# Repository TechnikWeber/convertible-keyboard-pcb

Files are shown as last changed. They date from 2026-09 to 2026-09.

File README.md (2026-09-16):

**English** · [Deutsch](README.de.md)

# convertible-keyboard-pcb

> ### 🔎 Looking for a case designer
> This keyboard has a PCB in progress but no case yet. If you design keyboard
> cases — 3D-printed, CNC-milled or laser-cut — and would like to take this on,
> please [open an issue](https://github.com/TechnikWeber/convertible-keyboard-pcb/issues).
> A first board outline exists (key field + 1.3 mm), but outline, mounting holes
> and the USB-C position can still be shaped around your case design — for the full-size board, the TKL, or
> both. The same goes for where exactly the lock indicators sit. The USB port
> can sit on the PCB or on a Unified Daughterboard (Pico-EZmate or JST-SH).

**One keyboard PCB, two sizes.** A full-size ISO-DE / ANSI board whose numpad
snaps off along a breakaway line. What remains is a complete tenkeyless (TKL)
keyboard — same PCB, same controller, same firmware.

This is not meant to be yet another one-off DIY keyboard. The goal is a
standardised core design that others can build on: cheap and simple to make, but
clean and modern — current KiCad, QMK, USB-C and parts that can actually be
bought. A case, lighting or layout variants build on this core instead of
bending it into something else.

> **Status: early.** The schematic is complete — key matrix, ANSI alternatives,
> backlight and controller — and every part has its footprint on the PCB.
> Controller, USB and drivers are placed on the back, board outline and breakaway
> line are drawn; mounting holes and routing are still to do.
> Nothing has been manufactured yet.

## Full-size or TKL

- The numpad sits on the right-hand side behind a 2 mm slot, held by four
  mouse-bite tabs (perforated breakaway bridges). Each tab keeps a hole-free
  channel in the middle for the traces that cross over.
- Controller, USB-C and the drivers for backlight and lock indicators all sit
  on the TKL part. Only the numpad's matrix, backlight and indicator lines cross the breakaway
  line.
- Snap the numpad off and the TKL keeps working unchanged — the numpad keys are
  simply gone. The firmware describes both layouts.
- The lock indicators above the numpad go with it – without a numpad Num Lock is
  pointless anyway; for the TKL populate the Caps Lock indicator above Page Up.
- The snapped-off numpad has no controller of its own and does not work on its
  own.

## Specs

- Full-size: 105 keys ISO-DE, key field 428.6 × 123.8 mm (22.5 × 6.5 u)
- TKL: 88 keys ISO-DE, key field 347.7 × 123.8 mm (18.25 × 6.5 u)
- ISO-DE and ANSI on one PCB: alternative positions for Enter, left Shift and
  backslash (the ANSI backslash is the only key without an LED)
- Cherry MX-compatible switches, soldered, with stabilizer holes on all keys of
  2u and wider
- 6 × 21 diode matrix (SOD-123)
- RP2040 controller with 16 Mbit QSPI flash, RESET and BOOTSEL buttons and SWD
  test pads
- USB-C (USB 2.0) on the board with ESD protection, 500 mA polyfuse and a 3.3 V
  LDO – or a Unified Daughterboard instead: connectors for Molex Pico-EZmate
  (uDB S1, C4, C5-EZM) and JST-SH (uDB C3, C5-JSH) are provided, not populated
- Single-colour backlight with reverse-mount 1206 LEDs on the back of the PCB
  (white, XINGLIGHT XL-3216UWC-FB), machine-assembled; switched, dimmed and
  "breathing" via QMK. A THT-LED variant uses the same design with different LED
  footprints
- Checked alternative backlight LEDs for the same footprint: MEIHUA MHT151WDT
  (LCSC C401114) and TUOZHAN P2-1206WYCS2-0.9T-F (LCSC C2827252)
- Caps Lock and Num Lock indicators (0805) above the numpad; for the TKL a Caps
  Lock indicator above Page Up is prepared but not populated
- All 30 RP2040 GPIOs in use: 27 matrix lines, backlight PWM, Caps Lock and
  Num Lock

## Repository

| Path | Contents |
|---|---|
| `convertible-keyboard-pcb.kicad_pro` / `.kicad_pcb` | KiCad 10 project and PCB |
| `convertible-keyboard-pcb.kicad_sch` | Root sheet: key matrix and ANSI alternatives |
| `backlight.kicad_sch` | Key LEDs, series resistors and MOSFET drivers |
| `mcu.kicad_sch` | RP2040, flash, crystal, USB-C and power |
| `lib/keyboard.pretty` | Project footprints: reverse-mount LED, THT LED for the variant |
| `fp-lib-table`, `convertible-keyboard-pcb.kicad_dru` | Footprint library table, design rule for the LED cutouts |
| `lib/MX_Alps_Hybrid` | Switch footprints by ai03 (git submodule) |
| `tools/` | Scripts that generated the sheets and updated the PCB – see [tools/README.md](tools/README.md) |
| `docs/production/` | Gerbers, drill file, BOM and placement file for JLCPCB |
| `firmware/` | QMK keyboard definition and keymaps – see [firmware/README.md](firmware/README.md) |

The footprints come from a submodule, so clone with:

```bash
git clone --recurse-submodules https://github.com/TechnikWeber/convertible-keyboard-pcb.git
```

## What it looks like

These renders let you review the design without installing KiCad.

### Key layouts

Everything is built around these two: ISO-DE with 105 keys and ANSI with 104. The board carries both. The ANSI
positions are alternative footprints that stay unpopulated on an ISO build, and the other way round.

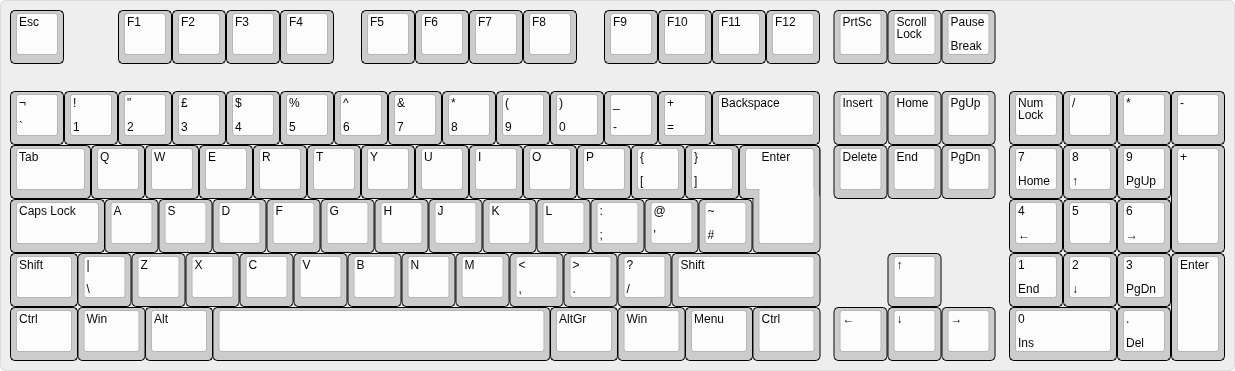
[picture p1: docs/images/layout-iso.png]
ISO-DE layout


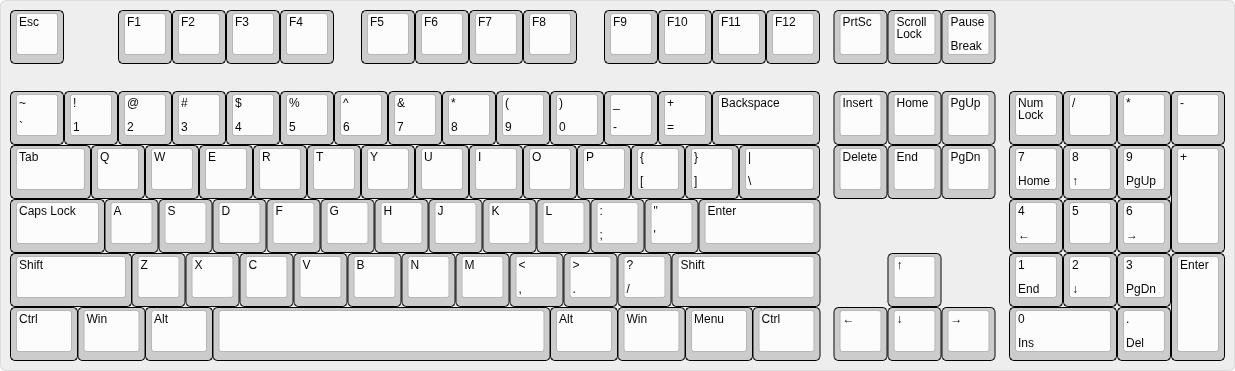
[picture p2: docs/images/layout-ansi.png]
ANSI layout


### Board in 3D

Switch side: through holes for the switches and their stabilisers, no components. Note the breakaway line in
front of the numpad.

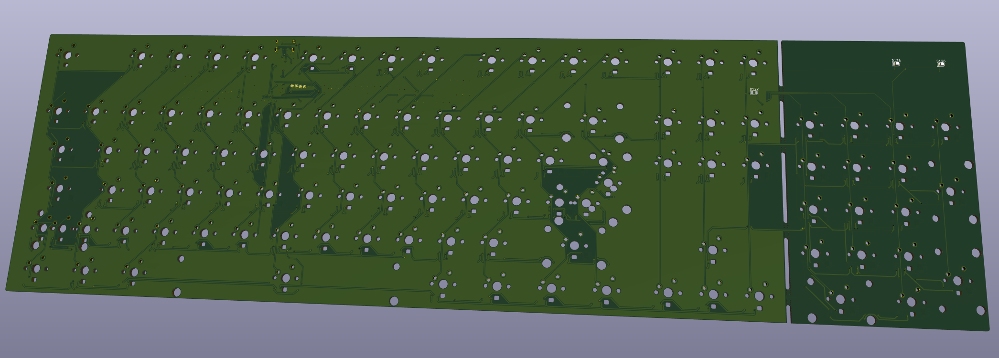
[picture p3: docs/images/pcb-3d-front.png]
3D, switch side


Component side: nearly everything sits here. Diodes and resistors per key, the reverse-mount LEDs shining
through their cutouts, and the controller in the gap between F4 and F5. The only parts on the other side are
the two lock indicators above the numpad.

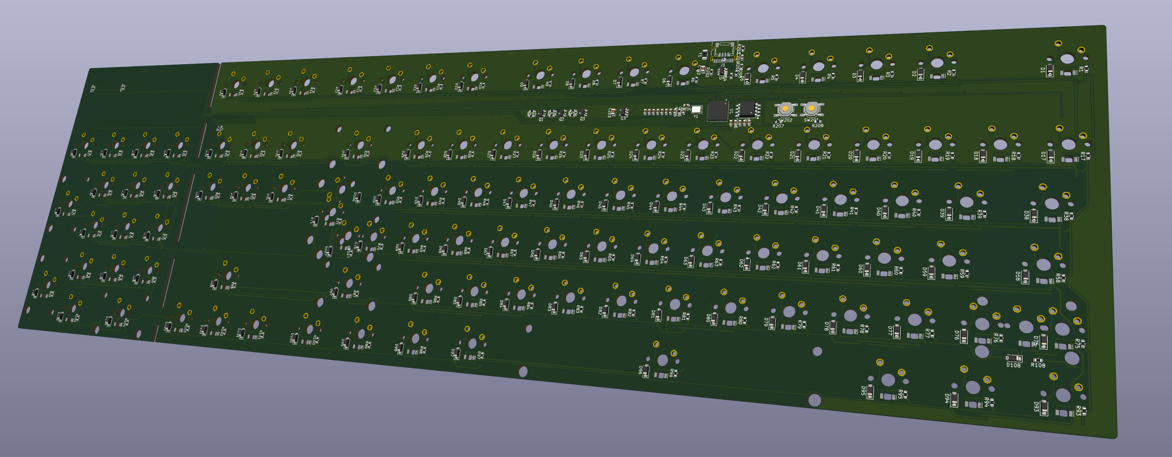
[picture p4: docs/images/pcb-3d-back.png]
3D, component side


### Board

Both copper layers, zone fills hidden so the traces stay readable. The numpad on the right snaps off along the
breakaway line; only matrix lines, +5V, BL_K and the two lock-LED lines cross it, through the four tabs.

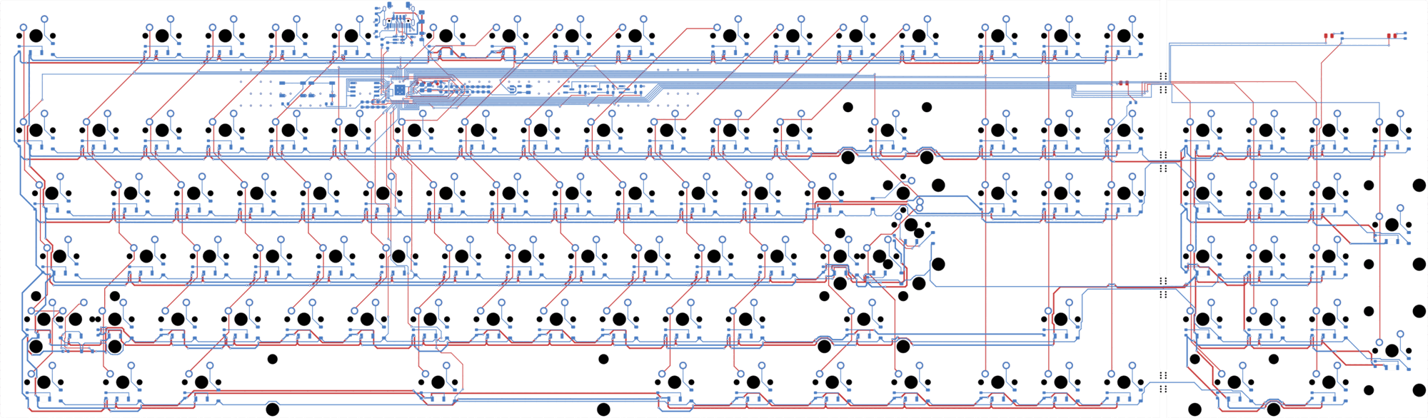
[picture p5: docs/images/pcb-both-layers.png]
Both copper layers


The controller sits in the gap between F4 and F5. Column and row buses run in fixed lanes and each one ends on a
via that drops onto the column trace of its key. Every SMD part in this area is on the back.

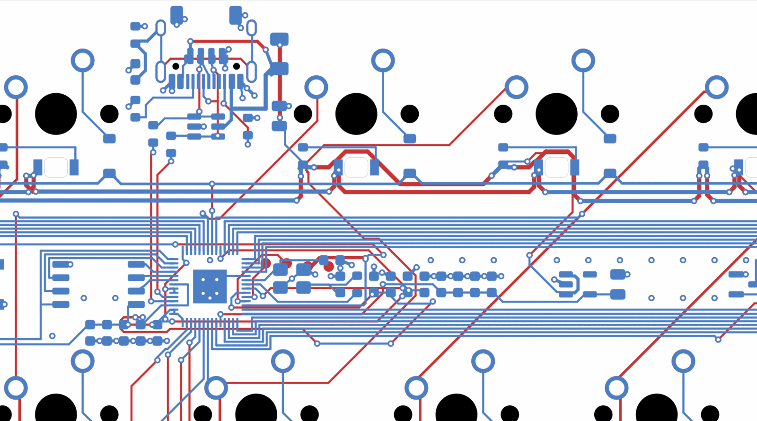
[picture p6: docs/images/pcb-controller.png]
Controller area


Front (switch side, mostly through holes and the key matrix) and back (all components, reverse-mount LEDs):

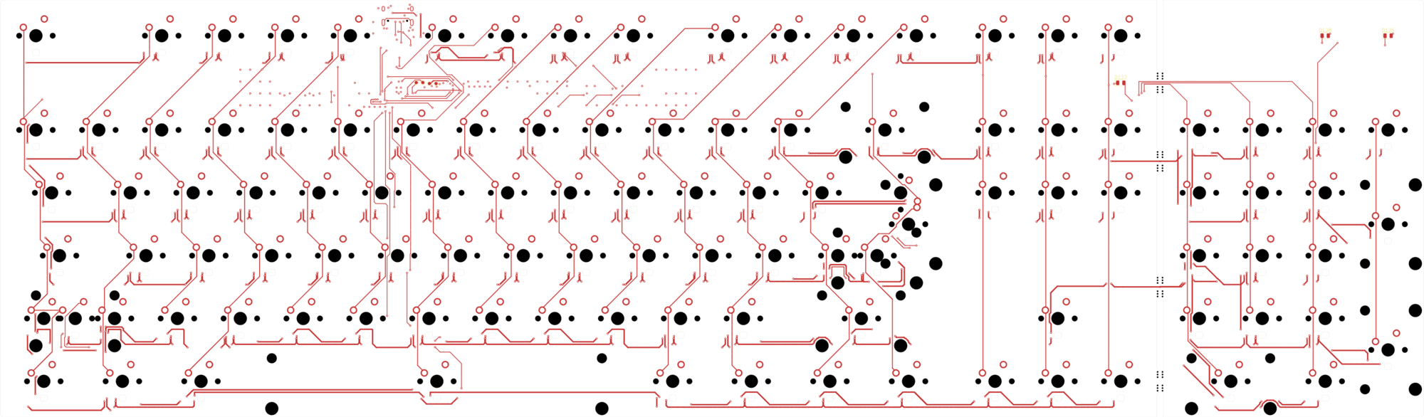
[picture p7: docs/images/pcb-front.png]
Front


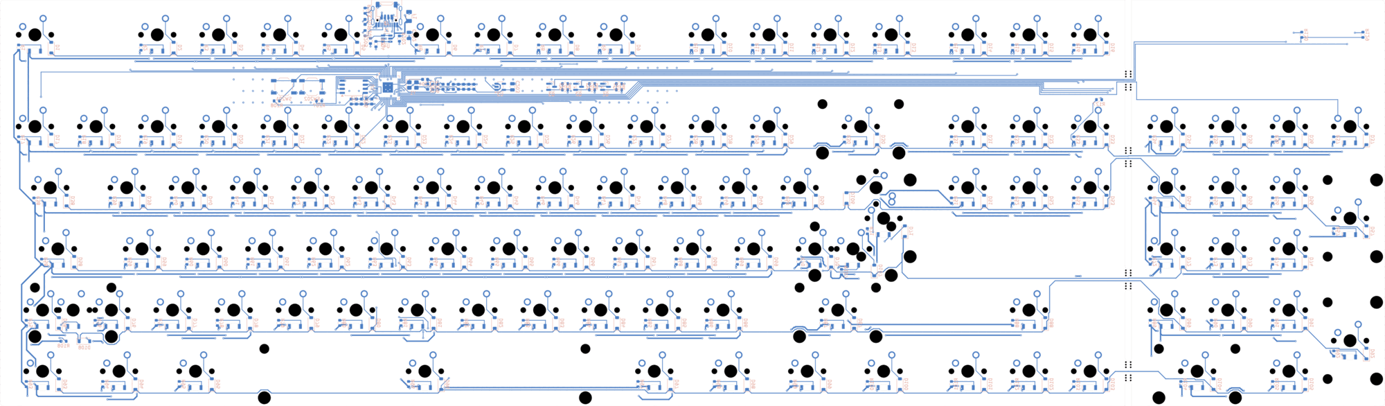
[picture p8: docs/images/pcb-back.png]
Back


### Schematic

Key matrix with the ANSI alternatives:

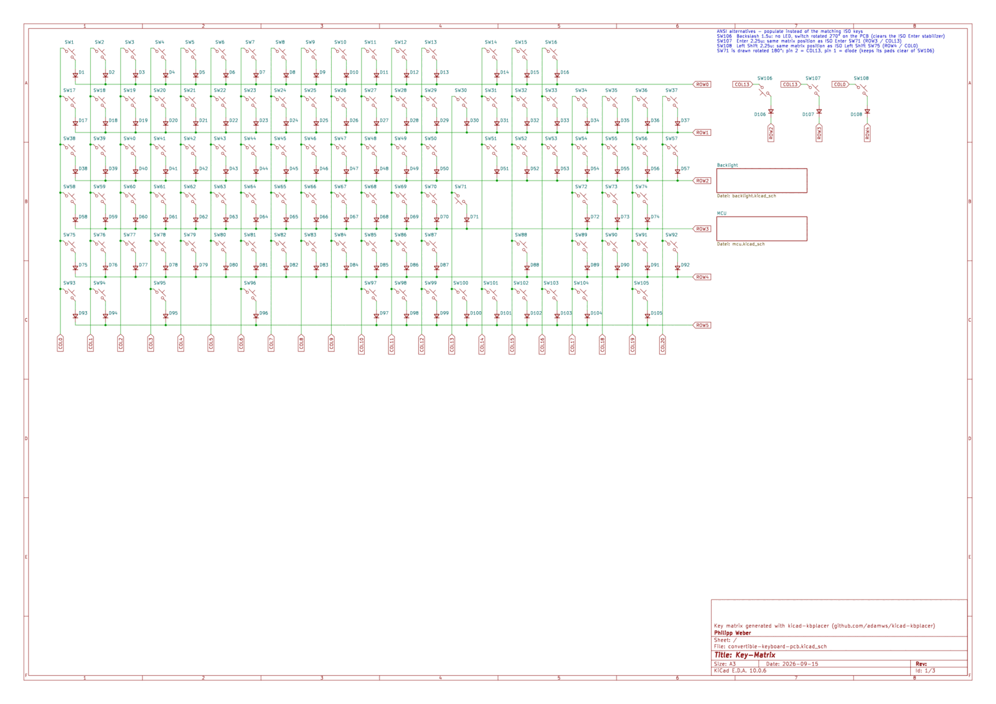
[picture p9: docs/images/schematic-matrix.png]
Matrix


Backlight, lock indicators and their drivers:

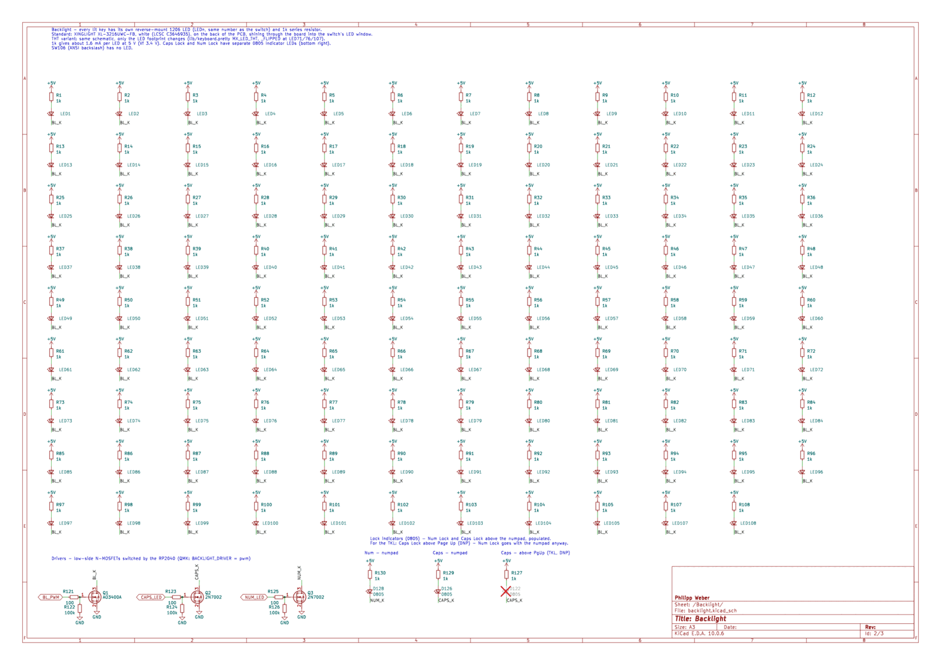
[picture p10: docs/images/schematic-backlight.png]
Backlight


Controller: RP2040, flash, crystal, LDO, USB-C with ESD protection, daughterboard connectors, buttons, test pads:

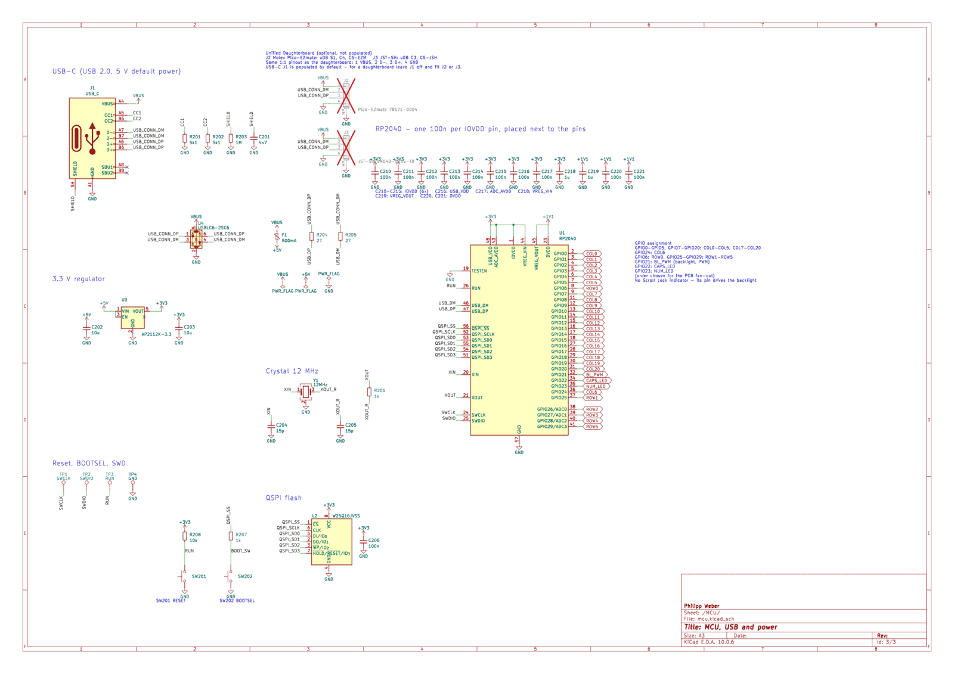
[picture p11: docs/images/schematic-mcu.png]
Controller


## Having it made

Gerbers, drill file, BOM and placement file for JLCPCB are in
[`docs/production/`](docs/production/README.md), all generated from the KiCad project. The board is
431.225 × 126.425 mm on two layers. 371 parts are machine-assembled; the 108 MX switches are soldered by
hand, and three parts are deliberately left unpopulated.

JLCPCB's minimum order is 5 boards: **$45 for five bare PCBs**, or **$112 for five with two of them
assembled** (checked 2026-09-16, shipping in, customs out). Switches, keycaps and a case come on top.

Nothing here has been built in hardware yet. The files pass DRC and schematic parity, nothing more —
review them before you spend money.

## Roadmap

- [x] Key matrix and diodes
- [x] Footprints for all key sizes
- [x] ANSI alternative positions
- [x] Single-colour backlight
- [x] Controller sheet: RP2040, flash, crystal, LDO, USB-C, ESD protection
- [x] Breakaway line for the numpad
- [x] Board outline (first draft)
- [x] Mounting holes: 14 × M2, placed in the free areas; final positions together with the case designer
- [x] Placement of controller, USB and drivers (preliminary)
- [x] Routing complete: key matrix and controller area (DRC clean, schematic parity clean, no open nets)
- [x] Manufacturing files for JLCPCB: gerbers, drill, BOM and placement file, an LCSC number on every part
- [x] Firmware (QMK): four layouts (full-size and TKL, each ISO and ANSI), matrix generated from the
      board file, backlight and lock indicators; compiles, not yet run on hardware

## Licence

CC BY-NC-SA 4.0 — see [LICENSE](LICENSE). The switch footprints in
`lib/MX_Alps_Hybrid` are by ai03 under the MIT License;
the THT LED footprints in `lib/keyboard.pretty` use their pad geometry.

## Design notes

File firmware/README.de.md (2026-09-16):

[English](README.md) · **Deutsch**

# Firmware (QMK)

QMK-Definition für die convertible-keyboard-pcb. Die Matrixzuordnung und die
Tastenreihenfolge aller Layout-Makros werden **aus der KiCad-Platine erzeugt**,
nicht von Hand getippt — die Firmware kann also nicht von der Platine
abdriften.

> **Kompiliert, aber noch nie auf Hardware gelaufen.** Alle vier Varianten
> bauen bis zum `.uf2` durch, `qmk lint` ist sauber. Es gibt noch keine Platine,
> auf der sie sich testen ließen.

## Layouts

| Layout-Makro | Tasten | Keymap-Ordner |
|---|---|---|
| `LAYOUT_fullsize_iso` | 105 | `keymaps/default` |
| `LAYOUT_fullsize_ansi` | 104 | `keymaps/fullsize_ansi` |
| `LAYOUT_tkl_iso` | 88 | `keymaps/tkl_iso` |
| `LAYOUT_tkl_ansi` | 87 | `keymaps/tkl_ansi` |

Die TKL-Varianten sind die, die man **nach** dem Abbrechen des Ziffernblocks
aufspielt. Alle vier sind als QMK-Community-Layouts angemeldet, fremde Keymaps
für andere `fullsize_iso`- oder `tkl_ansi`-Tastaturen laufen also unverändert.

## Bauen

Dieser Ordner ist die Quelle. Ihn in eine QMK-Arbeitskopie verlinken, statt zu
kopieren:

```sh
git clone --depth 1 --recurse-submodules https://github.com/qmk/qmk_firmware.git
mkdir -p qmk_firmware/keyboards/technikweber
ln -s "$(pwd)/technikweber/convertible" qmk_firmware/keyboards/technikweber/convertible

python3 -m venv qmkenv && ./qmkenv/bin/pip install qmk
export QMK_HOME="$(pwd)/qmk_firmware"
./qmkenv/bin/qmk compile -kb technikweber/convertible -km default
```

Statt `-km default` auch `fullsize_ansi`, `tkl_iso` oder `tkl_ansi`. Es braucht
eine `arm-none-eabi-gcc`; jede generische ARM-Toolchain genügt, es muss nicht
die aus QMKs eigenem Installationsskript sein.

## Aufspielen

Die Platine in den Bootloader bringen — Esc beim Einstecken halten, `SW201` auf
der Rückseite drücken, `SW202` (BOOTSEL) beim Einstecken halten oder `Fn` + `Esc`
— dann die `.uf2` auf das erscheinende Laufwerk `RPI-RP2` kopieren, oder statt
`qmk compile` einfach `qmk flash` benutzen.

## Fn-Ebene

`Fn` liegt auf der Menü-Taste, die unter ISO-DE praktisch ungenutzt ist. Die
Menü-Funktion selbst bleibt als `Fn` + Menü erreichbar.

| Taste | Funktion |
|---|---|
| `Fn` + `Esc` | Bootloader |
| `Fn` + `F1` | Beleuchtung an/aus |
| `Fn` + `F2` / `F3` | dunkler / heller |
| `Fn` + `F4` | Breathing an/aus |

## Zuordnung zur Hardware

21 Spalten × 6 Reihen, Dioden `COL2ROW`. Alle 30 GPIOs sind belegt: `GP0`–`GP5`
und `GP7`–`GP20` plus `GP24` für die Spalten, `GP6` und `GP25`–`GP29` für die
Reihen, `GP21` Beleuchtung, `GP22` Caps Lock, `GP23` Num Lock.

Die Beleuchtung läuft über PWM. Beim RP2040 gehört ein GPIO zum Slice
`(n / 2) % 8`, Kanal A bei geradem und B bei ungeradem Pin — `GP21` braucht
also `PWMD2` und Kanal B, genau das setzt `config.h`, während `halconf.h` und
`mcuconf.h` die Peripherie freischalten. Ohne diese drei Dateien fällt der Bau
auf eine STM32-Vorgabe (`PWMD4`) zurück und scheitert.

## USB-VID/PID

`0xFEED` / `0x0001` sind QMKs Platzhalter und kollidieren mit vielen anderen
Tastaturen. Zum Testen in Ordnung; wer das in Stückzahl baut, sollte eigene
Kennungen anmelden.

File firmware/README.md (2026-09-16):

**English** · [Deutsch](README.de.md)

# Firmware (QMK)

QMK keyboard definition for the convertible-keyboard-pcb. The matrix assignment
and the key order of every layout macro are **generated from the KiCad board
file**, not typed by hand — so the firmware cannot drift away from the PCB.

> **Compiled, not yet run on hardware.** All four variants build to a `.uf2`,
> and `qmk lint` passes. No board exists yet to test them on.

## Layouts

| Layout macro | Keys | Keymap folder |
|---|---|---|
| `LAYOUT_fullsize_iso` | 105 | `keymaps/default` |
| `LAYOUT_fullsize_ansi` | 104 | `keymaps/fullsize_ansi` |
| `LAYOUT_tkl_iso` | 88 | `keymaps/tkl_iso` |
| `LAYOUT_tkl_ansi` | 87 | `keymaps/tkl_ansi` |

The TKL variants are the ones to flash **after** snapping the numpad off. All
four are registered as QMK community layouts, so keymaps written for any other
`fullsize_iso` or `tkl_ansi` board can be used as-is.

## Building

This folder is the source of truth. Link it into a QMK checkout rather than
copying it:

```sh
git clone --depth 1 --recurse-submodules https://github.com/qmk/qmk_firmware.git
mkdir -p qmk_firmware/keyboards/technikweber
ln -s "$(pwd)/technikweber/convertible" qmk_firmware/keyboards/technikweber/convertible

python3 -m venv qmkenv && ./qmkenv/bin/pip install qmk
export QMK_HOME="$(pwd)/qmk_firmware"
./qmkenv/bin/qmk compile -kb technikweber/convertible -km default
```

Swap `-km default` for `fullsize_ansi`, `tkl_iso` or `tkl_ansi`. An
`arm-none-eabi-gcc` is required; any generic ARM build works, it does not have
to be the one from QMK's own installer.

## Flashing

Put the board into the bootloader — hold Escape while plugging it in, press
`SW201` on the back, hold `SW202` (BOOTSEL) while plugging in, or press
`Fn` + `Escape` — then drop the `.uf2` onto the `RPI-RP2` drive that appears, or
run `qmk flash` instead of `qmk compile`.

## Fn layer

`Fn` sits on the Menu key, which is unused on most ISO-DE setups. The Menu key
itself stays reachable as `Fn` + Menu.

| Key | Function |
|---|---|
| `Fn` + `Esc` | Bootloader |
| `Fn` + `F1` | Backlight on/off |
| `Fn` + `F2` / `F3` | Dimmer / brighter |
| `Fn` + `F4` | Breathing on/off |

## Hardware mapping

21 columns × 6 rows, diodes `COL2ROW`. All 30 GPIOs are in use: `GP0`–`GP5` and
`GP7`–`GP20` plus `GP24` for the columns, `GP6` and `GP25`–`GP29` for the rows,
`GP21` backlight, `GP22` Caps Lock, `GP23` Num Lock.

The backlight runs on PWM. On RP2040 a GPIO maps to slice `(n / 2) % 8`, channel
A on even and B on odd pins — `GP21` therefore needs `PWMD2` and channel B,
which is what `config.h` sets, with `halconf.h` and `mcuconf.h` enabling the
peripheral. Without those three files the build falls back to an STM32 default
(`PWMD4`) and fails.

## USB VID/PID

`0xFEED` / `0x0001` are QMK's placeholders and collide with plenty of other
boards. They are fine for testing; anyone producing these in numbers should
register their own.

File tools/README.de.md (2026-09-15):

[English](README.md) · **Deutsch**

# tools

Skripte, mit denen die Schaltplanblätter erzeugt und die Platine für
ANSI-Alternativen, Beleuchtung und Controller aktualisiert wurden. Sie bleiben im
Repository, damit der Entwurf nachvollziehbar ist und man darauf aufbauen kann.

> **Maßgeblich sind die KiCad-Dateien.** `build.sh` beginnt wieder beim
> kbplacer-Basis-Commit und überschreibt Schaltplan und Platine – alles, was
> seitdem in KiCad von Hand geändert wurde, geht verloren. Also auf einem Branch
> verwenden, oder um den erzeugten Stand vor Beginn des Layouts nachzubauen und
> zu erweitern.
>
> Der erzeugte Stand endet mit Commit `2eb5d4f`. Spätere Änderungen – Titelblöcke
> und Blattgrößen, die reduzierten Lock-Anzeigen – wurden direkt in KiCad gemacht.

## Ablauf

| Datei | Aufgabe |
|---|---|
| `build.sh --overwrite` | Führt die drei Schritte unten aus; verweigert den Start, solange KiCad das Projekt geöffnet hat |
| `gen_sch.py <Stufe>` | Baut den Schaltplan auf dem kbplacer-Hauptblatt auf (Basis-Commit `95ce8fa`). Stufe 1: ANSI-Alternativen, 2: Beleuchtung, 3: MCU-Blatt. Schreibt auch `lib/keyboard.kicad_sym` und `sym-lib-table`. UUIDs sind deterministisch |
| `check_sch.py` | Normalisiert die Dateien (`kicad-cli sch upgrade`), führt den ERC aus, exportiert die Netzliste und prüft jede erzeugte Verbindung gegen ihr Soll-Netz |
| `sync_pcb.py` | Aktualisiert die Platine aus der Netzliste wie „PCB aus Schaltplan aktualisieren“: tauscht und ergänzt Footprints, setzt Dioden und LED-Widerstände neben ihren Schalter, verknüpft Footprints mit Symbolen, vergibt Netze, führt den DRC mit Schaltplan-Parität aus |
| `place_override.json` | Dioden-/Widerstandspositionen, die von der Standardlage neben dem Schalter abweichen (ISO/ANSI-Kollisionen) |
| `kicadlib.py` | Minimaler S-Expression-Parser/-Serializer und Hilfen für Symbolbibliotheken |
| `led_variant.py smd\|tht` | Stellt die Tasten-LEDs in den aktuellen KiCad-Dateien zwischen Reverse-Mount-SMD (Standard) und THT um – nur die LED-Footprints ändern sich; führt ERC und DRC aus |
| `analysis/` | Kollisionsprüfungen zwischen ISO- und ANSI-Footprints, aus denen der gedrehte, unbeleuchtete ANSI-Backslash und die gespiegelten LED-Pads folgen |

## Verwendung

```bash
tools/build.sh --overwrite
```

Voraussetzungen: KiCad 10 mit `kicad-cli` und dem Python-Modul `pcbnew` sowie die
Git-Historie (die Basisdateien werden mit `git show` gelesen). Zwischendateien
landen in `tools/build/`.

pcbnew vergibt neu eingefügten Footprints frische UUIDs, deshalb ändert sich die
Platinendatei bei jedem Lauf, auch wenn elektrisch alles gleich bleibt; die
Schaltplandateien entstehen exakt gleich.

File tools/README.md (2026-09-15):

**English** · [Deutsch](README.de.md)

# tools

Scripts that generated the schematic sheets and updated the PCB for the ANSI
alternatives, the backlight and the controller. They are kept so the design can
be traced and built upon.

> **The KiCad files are the source of truth.** `build.sh` starts again from the
> kbplacer base commit and overwrites schematic and PCB – any manual work done in
> KiCad since then is lost. Use it on a branch, or to reproduce and extend the
> generated state before the layout begins.
>
> The generated state ends at commit `2eb5d4f`. Later changes – title blocks and
> sheet sizes, the reduced lock indicators – were made directly in KiCad.

## Pipeline

| File | What it does |
|---|---|
| `build.sh --overwrite` | Runs the three steps below; refuses to run while KiCad has the project open |
| `gen_sch.py <stage>` | Builds the schematic on top of the kbplacer root sheet (base commit `95ce8fa`). Stage 1: ANSI alternatives, 2: backlight, 3: MCU sheet. Also writes `lib/keyboard.kicad_sym` and `sym-lib-table`. UUIDs are deterministic |
| `check_sch.py` | Normalises the files (`kicad-cli sch upgrade`), runs ERC, exports the netlist and checks every generated connection against its expected net |
| `sync_pcb.py` | Updates the PCB from the netlist like "Update PCB from Schematic": swaps and adds footprints, places diodes and LED resistors next to their switch, links footprints to symbols, assigns nets, runs DRC with schematic parity |
| `place_override.json` | Diode/resistor positions that differ from the default next to the switch (ISO/ANSI collisions) |
| `kicadlib.py` | Minimal S-expression parser/serializer and symbol-library helpers |
| `led_variant.py smd\|tht` | Switches the key LEDs between reverse-mount SMD (standard) and THT on the current KiCad files – only the LED footprints change; runs ERC and DRC |
| `analysis/` | Collision checks between ISO and ANSI footprints that led to the rotated, unlit ANSI backslash and the flipped LED pads |

## Usage

```bash
tools/build.sh --overwrite
```

Requires KiCad 10 with `kicad-cli` and the `pcbnew` Python module, and the git
history (the base files are read with `git show`). Intermediate files go to
`tools/build/`.

pcbnew gives newly added footprints fresh UUIDs, so the PCB file changes on every
run even when nothing changed electrically; the schematic files are reproduced
exactly.

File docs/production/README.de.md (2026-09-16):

[English](README.md) · **Deutsch**

# Fertigungsdaten (JLCPCB)

Alles in diesem Ordner wird aus dem KiCad-Projekt im Hauptverzeichnis erzeugt.
Diese Dateien nicht von Hand bearbeiten — bei jeder Änderung an der Platine neu
erzeugen (siehe unten).

> **Noch nicht bestellt, noch nicht in Hardware geprüft.** Die Dateien bestehen
> DRC und Schaltplan-Parität, aber es wurde noch kein Prototyp daraus gebaut.
> Vor dem Geldausgeben selbst prüfen.

| Datei | Inhalt |
|---|---|
| `gerber.zip` | Gerber X1 + Excellon-Bohrdatei, direkt hochladbar |
| `BOM.csv` | Stückliste mit den Spaltennamen von JLCPCB |
| `CPL.csv` | Bestückungsdaten (Pick and Place) |

## Platine

| | |
|---|---|
| Größe | 431,225 × 126,425 mm |
| Lagen | 2 (35 µm Kupfer) |
| Min. Leiterbahn / Abstand | 0,2 mm / 0,15 mm |
| Min. Bohrung | 0,3 mm (Vias), NPTH bis herunter zu 0,5 mm (Mouse Bites) |
| Befestigungslöcher | 14 × Ø 2,2 mm für M2, nicht durchkontaktiert |
| Umriss | enthält den Sollbruch-Schlitz und seine vier Mouse-Bite-Stege |

Die `.drl`-Datei enthält durchkontaktierte und nicht durchkontaktierte Löcher
gemeinsam — falls JLCPCB fragt: **mixed plating**. Der Bohrursprung ist absolut,
Bohrdatei und Gerber liegen also im selben Koordinatensystem.

## Bestückung

371 Bauteile in 25 Gruppen. **369 sitzen auf der Unterseite, 2 auf der
Oberseite** (`D126`, `D128`, die Num- und Caps-Lock-Anzeigen über dem
Ziffernblock). Damit ist es ein beidseitiger Bestückungsauftrag, der spürbar
mehr kostet als ein einseitiger. Wer die Lock-Anzeigen nicht braucht, lässt
diese beiden Teile weg und bestückt nur die Unterseite.

Bewusst **nicht** in BOM und CPL:

- `SW1`–`SW108` — MX-Schalter werden von Hand gelötet, nicht von JLCPCB bestückt.
- `J2`, `J3` — Anschlüsse fürs Unified Daughterboard, DNP. Einen davon
  *anstelle* von `J1` bestücken, wenn die USB-Buchse aufs Daughterboard soll.
- `D122` — Caps-Lock-Anzeige der TKL-Variante, DNP. Erst sinnvoll, wenn der
  Ziffernblock abgebrochen ist; dann von Hand nachlöten.

Die Tasten-LEDs (`LED1`–`LED108`, ohne `LED106`) sind Reverse-Mount-Typen, die
*durch* die Platine leuchten, und sitzen deshalb wie alles andere unten.

## Was es kostet

JLCPCB fertigt ab **5 Platinen**. Preise vom 2026-09-16, in US-Dollar, Versand
enthalten, Zoll und Einfuhrumsatzsteuer **nicht**:

| Bestellung | Preis | Je Platine |
|---|---|---|
| 5 unbestückte Platinen, Standard Global Direct Line | 45 $ | 9 $ |
| 5 Platinen, davon 2 bestückt, Euro Packet | 112 $ | — |

Mit der bestückten Bestellung sollte man rechnen: Eine einzelne bestückte
Platine gibt es nicht, und die beiden bestückten tragen den Großteil der 112 $.
Schalter, Tastenkappen, Stabilisatoren und ein Gehäuse kommen obendrauf und
stecken in keiner JLCPCB-Bestellung.

## Bestellen

1. **Platine:** `gerber.zip` hochladen. Voreinstellungen
   passen; 2 Lagen, 1,6 mm, HASL genügt. Schlitz und Mouse Bites stecken im
   Umriss, es braucht keine Sonderhinweise.
2. **Bestückung:** einschalten, **beide Seiten** wählen, `BOM.csv` und `CPL.csv`
   hochladen. JLCPCB liest die LCSC-Nummer aus der Spalte `LCSC Part #`, die
   Teile sollten also automatisch zugeordnet werden.
3. Die Bestückungsvorschau prüfen, besonders die Drehung von `U1` (RP2040),
   `U3` (LDO), `U4` (ESD-Array) und der Dioden. Die Winkel in `CPL.csv` folgen
   der KiCad-Konvention, der JLCPCB meistens — aber nicht immer — folgt.

## Neu erzeugen

Im Hauptverzeichnis, mit installiertem KiCad 10:

```sh
kicad-cli pcb drc --refill-zones --save-board --schematic-parity \
    --format json -o /tmp/drc.json convertible-keyboard-pcb.kicad_pcb
kicad-cli pcb export gerbers --no-x2 --subtract-soldermask \
    -o /tmp/gerber convertible-keyboard-pcb.kicad_pcb
kicad-cli pcb export drill --drill-origin absolute --excellon-units mm \
    --generate-map --map-format gerberx2 -o /tmp/gerber convertible-keyboard-pcb.kicad_pcb
```

Immer zuerst die Zonen neu füllen — eine veraltete Füllung erzeugt Phantom-
Abstandsfehler und, schlimmer, Gerber, die nicht zu der Platine passen, die man
geprüft hat.

**Das hochgeladene Archiv darf kein `convert` im Namen haben.** JLCPCB weist
solche Uploads ab – deshalb heißt es `gerber.zip` und nicht
`convertible-keyboard-pcb-gerber.zip`. Die zwölf Dateien *im* Archiv behalten
den Projektnamen und werden so akzeptiert.

`BOM.csv` und `CPL.csv` entstehen aus `kicad-cli sch export bom` und
`kicad-cli pcb export pos`, ohne die DNP-Teile und die handgelöteten Schalter
und mit den Spaltennamen, die JLCPCB erwartet. Die Y-Koordinaten in `CPL.csv`
sind negativ und passen damit zum Koordinatensystem der Gerber — das Vorzeichen
nicht umdrehen.

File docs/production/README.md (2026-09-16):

**English** · [Deutsch](README.de.md)

# Production files (JLCPCB)

Everything in this folder is generated from the KiCad project in the repository
root. Do not edit these files by hand — regenerate them (see the bottom of this
page) whenever the board changes.

> **Not yet ordered or verified in hardware.** These files have passed DRC and
> schematic parity, but no prototype has been built from them. Review them
> before spending money.

| File | What it is |
|---|---|
| `gerber.zip` | Gerber X1 + Excellon drill, ready to upload |
| `BOM.csv` | Bill of materials, JLCPCB column names |
| `CPL.csv` | Component placement (pick and place) |

## Board

| | |
|---|---|
| Size | 431.225 × 126.425 mm |
| Layers | 2 (1 oz copper) |
| Min. track / clearance | 0.2 mm / 0.15 mm |
| Min. drill | 0.3 mm (vias), NPTH down to 0.5 mm (mouse bites) |
| Mounting holes | 14 × Ø 2.2 mm for M2, non-plated |
| Board outline | includes the breakaway slot and its four mouse-bite tabs |

The `.drl` file contains plated and non-plated holes together — pick
**mixed plating** if JLCPCB asks. Drill origin is absolute, so the drill file
and the gerbers share the gerbers' coordinate system.

## Assembly

371 parts in 25 groups. **369 sit on the bottom side, 2 on the top** (`D126`,
`D128`, the Num-Lock and Caps-Lock indicators above the numpad). That makes it a
double-sided assembly job, which costs noticeably more than a single-sided one.
If you do not need the lock indicators, drop those two parts and the order
becomes bottom-side only.

Deliberately **not** in the BOM or CPL:

- `SW1`–`SW108` — MX switches are hand-soldered, not assembled by JLCPCB.
- `J2`, `J3` — Unified Daughterboard connectors, DNP. Fit one of them *instead*
  of `J1` if you want the USB port on a daughterboard.
- `D122` — Caps-Lock indicator for the TKL variant, DNP. Only useful once the
  numpad has been snapped off; solder it by hand then.

The key LEDs (`LED1`–`LED108`, minus `LED106`) are reverse-mount parts that
shine *through* the board, so they sit on the bottom side like everything else.

## What it costs

JLCPCB's minimum order is **5 boards**. Prices checked on 2026-09-16, in US
dollars, shipping included, customs and import VAT **not** included:

| Order | Price | Per board |
|---|---|---|
| 5 bare PCBs, Standard Global Direct Line | $45 | $9 |
| 5 PCBs, 2 of them assembled, Euro Packet | $112 | — |

The assembled order is the honest number to plan with: you cannot buy a single
assembled board, and the two populated ones carry most of the $112. Switches,
keycaps, stabilisers and a case are on top of this and are not part of any
JLCPCB order.

## Ordering

1. **PCB:** upload `gerber.zip`. Leave the defaults;
   2 layers, 1.6 mm, HASL is fine. The breakaway slot and mouse bites are part
   of the outline, so no extra instructions are needed.
2. **Assembly:** turn it on, choose **both sides**, upload `BOM.csv` and
   `CPL.csv`. JLCPCB reads the LCSC number from the `LCSC Part #` column, so the
   parts should be matched automatically.
3. Check the placement preview, especially the rotation of `U1` (RP2040),
   `U3` (LDO), `U4` (ESD array) and the diodes. Rotations in `CPL.csv` follow
   KiCad's convention, which JLCPCB usually — but not always — agrees with.

## Regenerating

From the repository root, with KiCad 10 installed:

```sh
kicad-cli pcb drc --refill-zones --save-board --schematic-parity \
    --format json -o /tmp/drc.json convertible-keyboard-pcb.kicad_pcb
kicad-cli pcb export gerbers --no-x2 --subtract-soldermask \
    -o /tmp/gerber convertible-keyboard-pcb.kicad_pcb
kicad-cli pcb export drill --drill-origin absolute --excellon-units mm \
    --generate-map --map-format gerberx2 -o /tmp/gerber convertible-keyboard-pcb.kicad_pcb
```

Always refill the zones first — a stale zone fill produces phantom clearance
errors and, worse, gerbers that do not match the board you checked.

**The uploaded archive must not have `convert` in its name.** JLCPCB rejects
such uploads, which is why it is called `gerber.zip` and not
`convertible-keyboard-pcb-gerber.zip`. The twelve files *inside* the archive
keep the project name and are accepted as they are.

`BOM.csv` and `CPL.csv` come from `kicad-cli sch export bom` and
`kicad-cli pcb export pos`, with the DNP parts and the hand-soldered switches
removed and the columns renamed to what JLCPCB expects. The Y coordinates in
`CPL.csv` are negative, matching the gerbers' coordinate system — do not flip
the sign.

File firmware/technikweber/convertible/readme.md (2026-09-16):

# convertible-keyboard-pcb

A full-size ISO-DE / ANSI keyboard whose numpad snaps off along a breakaway
line, leaving a complete TKL. Same PCB, same controller, same firmware — only
the layout macro changes.

* Keyboard maintainer: [TechnikWeber](https://github.com/TechnikWeber)
* Hardware supported: convertible-keyboard-pcb (RP2040)
* Hardware availability: [PCB sources and production files](https://github.com/TechnikWeber/convertible-keyboard-pcb)

The matrix assignment and the key order in every layout macro are generated from
the KiCad board file, not written by hand.

| Layout | Keys | When to use |
|---|---|---|
| `LAYOUT_fullsize_iso` | 105 | Full-size board, ISO (default keymap) |
| `LAYOUT_fullsize_ansi` | 104 | Full-size board, ANSI |
| `LAYOUT_tkl_iso` | 88 | Numpad snapped off, ISO |
| `LAYOUT_tkl_ansi` | 87 | Numpad snapped off, ANSI |

Make example for this keyboard (after setting up your build environment):

    qmk compile -kb technikweber/convertible -km default

Flashing example for this keyboard:

    qmk flash -kb technikweber/convertible -km default

See the [build environment setup](https://docs.qmk.fm/#/getting_started_build_tools)
and the [make instructions](https://docs.qmk.fm/#/getting_started_make_guide) for
more information. Brand new to QMK? Start with our [Complete Newbs Guide](https://docs.qmk.fm/#/newbs).

## Bootloader

Enter the bootloader in three ways:

* **Bootmagic reset**: hold Escape and plug in the keyboard
* **Physical reset button**: press `SW201` on the back of the PCB, or hold
  `SW202` (BOOTSEL) while plugging in
* **Keycode in layout**: press `Fn` + `Escape`

## Fn layer

`Fn` sits on the Menu key — it is unused on most ISO-DE setups, so nothing of
value is lost. On the Fn layer:

| Key | Function |
|---|---|
| `Fn` + `Esc` | Enter the bootloader for flashing |
| `Fn` + `F1` | Backlight on/off |
| `Fn` + `F2` / `F3` | Backlight dimmer / brighter |
| `Fn` + `F4` | Backlight breathing on/off |

## Hardware notes

The backlight is a single white LED per key on `GP21`, driven through a MOSFET;
with 1 kΩ series resistors the whole field draws roughly 170 mA, which keeps the
board inside the USB budget. Caps Lock and Num Lock indicators sit on `GP22` and
`GP23`. There is no Scroll Lock indicator.

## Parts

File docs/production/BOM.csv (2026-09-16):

Comment | Designator | Footprint | LCSC Part #
0603B472K500NT | C201 | C_0603_1608Metric | C53987
CL21A106KAYNNNE | C202,C203 | C_0805_2012Metric | C15850
CL10C150JB8NNNC | C204,C205 | C_0603_1608Metric | C1644
CC0603KRX7R9BB104 | C206,C210,C211,C212,C213,C214,C215,C216,C217,C220,C221 | C_0603_1608Metric | C14663
CL10A105KB8NNNC | C218,C219 | C_0603_1608Metric | C15849
1N4148W | D1,D2,D3,D4,D5,D6,D7,D8,D9,D10,D11,D12,D13,D14,D15,D16,D17,D18,D19,D20,D21,D22,D23,D24,D25,D26,D27,D28,D29,D30,D31,D32,D33,D34,D35,D36,D37,D38,D39,D40,D41,D42,D43,D44,D45,D46,D47,D48,D49,D50,D51,D52,D53,D54,D55,D56,D57,D58,D59,D60,D61,D62,D63,D64,D65,D66,D67,D68,D69,D70,D71,D72,D73,D74,D75,D76,D77,D78,D79,D80,D81,D82,D83,D84,D85,D86,D87,D88,D89,D90,D91,D92,D93,D94,D95,D96,D97,D98,D99,D100,D101,D102,D103,D104,D105,D106,D107,D108 | D_SOD-123 | C81598
KT-0805W | D126,D128 | LED_0805_2012Metric | C34499
SMD1206P050TF/15 | F1 | Fuse_1206_3216Metric | C106264
TYPE-C-31-M-12 | J1 | USB_C_Receptacle_HRO_TYPE-C-31-M-12 | C165948
XL-3216UWC-FB | LED1,LED2,LED3,LED4,LED5,LED6,LED7,LED8,LED9,LED10,LED11,LED12,LED13,LED14,LED15,LED16,LED17,LED18,LED19,LED20,LED21,LED22,LED23,LED24,LED25,LED26,LED27,LED28,LED29,LED30,LED31,LED32,LED33,LED34,LED35,LED36,LED37,LED38,LED39,LED40,LED41,LED42,LED43,LED44,LED45,LED46,LED47,LED48,LED49,LED50,LED51,LED52,LED53,LED54,LED55,LED56,LED57,LED58,LED59,LED60,LED61,LED62,LED63,LED64,LED65,LED66,LED67,LED68,LED69,LED70,LED71,LED72,LED73,LED74,LED75,LED76,LED77,LED78,LED79,LED80,LED81,LED82,LED83,LED84,LED85,LED86,LED87,LED88,LED89,LED90,LED91,LED92,LED93,LED94,LED95,LED96,LED97,LED98,LED99,LED100,LED101,LED102,LED103,LED104,LED105,LED107,LED108 | LED_1206_ReverseMount_XL-3216 | C3646935
AO3400A | Q1 | SOT-23 | C20917
2N7002 | Q2,Q3 | SOT-23 | C8545
0603WAF1001T5E | R1,R2,R3,R4,R5,R6,R7,R8,R9,R10,R11,R12,R13,R14,R15,R16,R17,R18,R19,R20,R21,R22,R23,R24,R25,R26,R27,R28,R29,R30,R31,R32,R33,R34,R35,R36,R37,R38,R39,R40,R41,R42,R43,R44,R45,R46,R47,R48,R49,R50,R51,R52,R53,R54,R55,R56,R57,R58,R59,R60,R61,R62,R63,R64,R65,R66,R67,R68,R69,R70,R71,R72,R73,R74,R75,R76,R77,R78,R79,R80,R81,R82,R83,R84,R85,R86,R87,R88,R89,R90,R91,R92,R93,R94,R95,R96,R97,R98,R99,R100,R101,R102,R103,R104,R105,R107,R108,R127,R129,R130,R206,R207 | R_0603_1608Metric | C21190
0603WAF1000T5E | R121,R123,R125 | R_0603_1608Metric | C22775
0603WAF1003T5E | R122,R124,R126 | R_0603_1608Metric | C25803
0603WAF5101T5E | R201,R202 | R_0603_1608Metric | C23186
0603WAF1004T5E | R203 | R_0603_1608Metric | C22935
0603WAF270JT5E | R204,R205 | R_0603_1608Metric | C25190
0603WAF1002T5E | R208 | R_0603_1608Metric | C25804
TL3342F260QG | SW201,SW202 | SW_SPST_TL3342 | C2886894
RP2040 | U1 | QFN-56-1EP_7x7mm_P0.4mm_EP3.2x3.2mm | C2040
W25Q16JVSSIQ | U2 | SOIC-8_5.3x5.3mm_P1.27mm | C82317
AP2112K-3.3TRG1 | U3 | SOT-23-5 | C51118
USBLC6-2SC6 | U4 | SOT-23-6 | C7519
X322512MSB4SI | Y1 | Crystal_SMD_3225-4Pin_3.2x2.5mm | C9002

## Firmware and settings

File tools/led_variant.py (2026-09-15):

#!/usr/bin/env python3
"""Switch the key LEDs between the standard reverse-mount SMD variant and the THT variant.

    tools/led_variant.py smd    LEDn = reverse-mount 1206 on the back of the PCB (standard)
    tools/led_variant.py tht    LEDn = THT LED through the switch LED slot

Only the LED footprints and their Value/LCSC fields change - schematic, nets and positions stay the same.
Edits the KiCad files in place, so close KiCad first. Runs ERC and DRC with schematic parity afterwards.
"""
import sys, os, json, subprocess, collections

HERE = os.path.dirname(os.path.abspath(__file__))
PRJ = os.path.dirname(HERE)
sys.path.insert(0, HERE)
from kicadlib import parse, dumps, find, findall

NAME = "convertible-keyboard-pcb"
BUILD = os.path.join(HERE, "build")
VARIANTS = {
    "smd": dict(fp="keyboard:LED_1206_ReverseMount_XL-3216", value="XL-3216UWC-FB", side="B",
                fields={"LCSC": "C3646935", "Manufacturer": "XINGLIGHT", "MPN": "XL-3216UWC-FB",
                        # checked against the footprint: body, lens and terminals fit
                        "LCSC Alternatives": "C401114 MEIHUA MHT151WDT; C2827252 TUOZHAN P2-1206WYCS2-0.9T-F"}),
    "tht": dict(fp="keyboard:MX_LED_THT", value="LED THT", side="F",
                fields={"LCSC": "", "Manufacturer": "", "MPN": "", "LCSC Alternatives": ""}),
}
# THT only: the square cathode pad would come too close to a stabilizer hole of an ISO/ANSI alternative key
THT_FLIPPED = {"LED71", "LED76", "LED107"}
KNOWN_DRC = {("error", "invalid_outline"), ("warning", "hole_to_hole"), ("warning", "silk_over_copper"),
             ("warning", "silk_overlap")}


def is_key_led(ref):
    return ref.startswith("LED") and ref[3:].isdigit()


def footprint_for(variant, ref):
    if variant == "tht" and ref in THT_FLIPPED:
        return "keyboard:MX_LED_THT_FLIPPED"
    return VARIANTS[variant]["fp"]


def schematic(variant):
    v = VARIANTS[variant]
    locked = any(f.startswith("~") and f.endswith(".lck") for f in os.listdir(PRJ))
    if subprocess.run(["pgrep", "-x", "kicad"], capture_output=True).returncode == 0 or locked:
        sys.exit("KiCad is running or the project is locked - close KiCad first.")
    os.makedirs(BUILD, exist_ok=True)
    path = os.path.join(PRJ, "backlight.kicad_sch")
    t = parse(open(path).read())
    changed = 0
    for s in findall(t, "symbol"):
        props = {p[1]: p for p in findall(s, "property")}
        ref = props["Reference"][2]
        if not is_key_led(ref):
            continue
        props["Footprint"][2] = footprint_for(variant, ref)
        props["Value"][2] = v["value"]
        for key, val in v["fields"].items():
            if key in props:
                props[key][2] = val
        changed += 1
    open(path, "w").write(dumps(t) + "\n")
    root = os.path.join(PRJ, f"{NAME}.kicad_sch")
    net = os.path.join(BUILD, "variant.net")
    subprocess.run(["kicad-cli", "sch", "upgrade", "--force", root], capture_output=True, check=True)
    subprocess.run(["kicad-cli", "sch", "erc", "--format", "json", "--severity-all",
                    "-o", os.path.join(BUILD, "erc_variant.json"), root], capture_output=True)
    subprocess.run(["kicad-cli", "sch", "export", "netlist", "--format", "kicadsexpr", "-o", net, root],
                   capture_output=True, check=True)
    erc = sum(len(sh["violations"]) for sh in json.load(open(os.path.join(BUILD, "erc_variant.json")))["sheets"])
    print(f"schematic: {changed} key LEDs -> {variant}, ERC violations: {erc}")
    if erc:
        sys.exit(1)
    # the PCB runs in its own process: pcbnew likes to segfault while Python tears down
    sys.exit(subprocess.run([sys.executable, os.path.abspath(__file__), "--pcb", variant, net]).returncode)


def pcb(variant, net):
    import pcbnew
    v = VARIANTS[variant]
    nl = parse(open(net).read())
    comps = {}
    for c in findall(find(nl, "components"), "comp"):
        ref = find(c, "ref")[1]
        if not is_key_led(ref):
            continue
        fields = {find(f, "name")[1]: (f[2] if len(f) > 2 and isinstance(f[2], str) else "")
                  for f in findall(find(c, "fields"), "field")} if find(c, "fields") else {}
        comps[ref] = dict(fp=find(c, "footprint")[1], value=find(c, "value")[1], fields=fields)
    pinnet = {}
    for n in findall(find(nl, "nets"), "net"):
        for nd in findall(n, "node"):
            pinnet[(find(nd, "ref")[1], find(nd, "pin")[1])] = find(n, "name")[1]

    path = os.path.join(PRJ, f"{NAME}.kicad_pcb")
    b = pcbnew.LoadBoard(path)
    old = {f.GetReference(): f for f in b.GetFootprints() if f.GetReference() in comps}
    missing = sorted(set(comps) - set(old))
    assert not missing, f"LED footprints missing on the PCB: {missing}"
    todo = []                                  # load everything before touching the board
    for ref, c in sorted(comps.items()):
        if old[ref].GetFPIDAsString() == c["fp"]:
            continue
        lib, name = c["fp"].split(":", 1)
        libdir = os.path.join(PRJ, "lib", "keyboard.pretty") if lib == "keyboard" \
            else f"/usr/share/kicad/footprints/{lib}.pretty"
        f = pcbnew.FootprintLoad(libdir, name)
        assert type(f).__name__ == "FOOTPRINT", (ref, c["fp"])
        f.SetFPID(pcbnew.LIB_ID(lib, name))
        todo.append((ref, old[ref], f))
    for ref, o, f in todo:
        b.Add(f)
        f.SetPosition(o.GetPosition())
        if v["side"] == "B":
            f.SetLayerAndFlip(pcbnew.B_Cu)
        f.SetOrientationDegrees(0)
        f.SetReference(ref)
        f.SetValue(comps[ref]["value"])
        f.SetPath(o.GetPath())
        f.SetSheetname(o.GetSheetname())
        f.SetSheetfile(o.GetSheetfile())
        f.SetDNP(o.IsDNP())
        for k, val in comps[ref]["fields"].items():
            if k not in ("Reference", "Value", "Footprint"):
                f.SetField(k, val)
                if k not in ("Datasheet", "Description") and f.GetField(k) is not None:
                    f.GetField(k).SetVisible(False)
        for pad in f.Pads():
            key = (ref, pad.GetNumber())
            if pad.GetNumber() and key in pinnet:
                ni = b.FindNet(pinnet[key])
                assert ni is not None, pinnet[key]
                pad.SetNet(ni)
    for ref, o, f in todo:                     # removals last
        b.Remove(o)
    b.Save(path)
    print(f"PCB: {len(todo)} LED footprints swapped")
    sys.stdout.flush()

    out = os.path.join(BUILD, "drc_variant.json")
    subprocess.run(["kicad-cli", "pcb", "drc", "--schematic-parity", "--severity-all", "--format", "json",
                    "-o", out, path], capture_output=True)
    d = json.load(open(out))
    cnt = collections.Counter((x["severity"], x["type"]) for x in d["violations"])
    parity = d.get("schematic_parity", [])
    print("DRC:", dict(cnt), "| parity:", len(parity))
    shown = collections.Counter()
    for x in d["violations"]:
        key = (x["severity"], x["type"])
        if key in KNOWN_DRC or shown[key] >= 8:
            continue
        shown[key] += 1
        print(f"  [{x['type']}] {x['description'][:70]} | " +
              " ; ".join(f"{i['description'][:50]} @({i['pos']['x']:.2f},{i['pos']['y']:.2f})" for i in x["items"]))
    sys.stdout.flush()
    os._exit(1 if parity or set(cnt) - KNOWN_DRC else 0)


if __name__ == "__main__":
    if len(sys.argv) == 4 and sys.argv[1] == "--pcb":
        pcb(sys.argv[2], sys.argv[3])
    elif len(sys.argv) == 2 and sys.argv[1] in VARIANTS:
        schematic(sys.argv[1])
    else:
        print(__doc__)
        sys.exit(2)

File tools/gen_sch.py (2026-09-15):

#!/usr/bin/env python3
"""Builds the schematic on top of the base root sheet.

Stage 1: ANSI alternatives (SW106-108, D106-108), ISO Enter pin swap.
Stage 2: backlight - SW_MX_LED symbols, LED units, resistors, MOSFET drivers.
Stage 3: MCU sheet - RP2040, flash, crystal, LDO, USB-C, ESD, buttons, SWD pads.
"""
import sys, os, json
HERE = os.path.dirname(os.path.abspath(__file__))
sys.path.insert(0, HERE)
from kicadlib import *
import uuid as _uuid

_UID_NS = _uuid.UUID("5b1f3c1e-6d2a-4c1b-9a8e-3f7d2c4b5a60")
_uid_counters = {}
_uid_ctx = ["root"]


def uid(key=None):
    """Deterministic UUIDs, counted per sheet: re-running the generator keeps symbol paths and PCB links
    stable, and additions on one sheet do not renumber the others."""
    if key is None:
        n = _uid_counters.get(_uid_ctx[0], 0)
        _uid_counters[_uid_ctx[0]] = n + 1
        key = f"{_uid_ctx[0]}:{n}"
    return str(_uuid.uuid5(_UID_NS, key))


PRJ = os.path.dirname(HERE)
OUT = os.path.join(HERE, "build")
NAME = "convertible-keyboard-pcb"
STAGE = int(sys.argv[1])
KBLIB = PRJ + "/lib/keyboard.kicad_sym"
U = 2.54
R0603 = "Resistor_SMD:R_0603_1608Metric"
C0603 = "Capacitor_SMD:C_0603_1608Metric"
C0805 = "Capacitor_SMD:C_0805_2012Metric"

EXPECT = {}
COUNT = {"#PWR": 0, "#FLG": 0}
POWER = {"GND", "+5V", "+3V3", "+1V1", "VBUS"}
GLOBAL = {f"ROW{i}" for i in range(6)} | {f"COL{i}" for i in range(21)} | {"BL_PWM", "CAPS_LED", "NUM_LED"}
ANG = {(1, 0): 0, (-1, 0): 180, (0, -1): 90, (0, 1): 270}
JUST = {0: "left", 90: "left", 180: "right", 270: "right"}


def prop(sym, key):
    for p in findall(sym, "property"):
        if p[1] == key:
            return p
    return None


def effects(justify=None, size=1.27):
    e = S("effects", S("font", S("size", size, size)))
    if justify:
        e.append([Sym("justify")] + [Sym(j) for j in justify.split()])
    return e


class Sheet:
    def __init__(self, tree, path):
        self.tree, self.path = tree, path
        self.libs = find(tree, "lib_symbols")

    def lib(self, lib, name):
        full = f"{lib}:{name}"
        for s in findall(self.libs, "symbol"):
            if s[1] == full:
                return s
        s = lib_symbol(lib, name, KBLIB if lib == "keyboard" else None)
        self.libs.append(s)
        return s

    def add(self, node):
        tail = 0
        while isinstance(self.tree[-1 - tail], list) and self.tree[-1 - tail][0] in ("sheet_instances", "embedded_fonts"):
            tail += 1
        self.tree.insert(len(self.tree) - tail, node)


class Placed:
    def __init__(self, libsym, ref, x, y, rot, unit):
        self.ref = ref
        self.pins = {}
        for p in pins(libsym):
            if p["unit"] in (0, unit):
                self.pins[p["num"]] = (to_screen(x, y, rot, p["x"], p["y"]), pin_dir(rot, p["a"]))
        self.byname = {}
        for p in pins(libsym):
            if p["unit"] in (0, unit):
                self.byname.setdefault(p["name"].split("/")[0], []).append(p["num"])

    def pin(self, n):
        return self.pins[n]


def symbol(sh, lib, name, ref, x, y, rot=0, unit=1, value=None, footprint="", fpos=None, hide_value=False,
           in_bom=True, dnp=False):
    ls = sh.lib(lib, name)
    fpos = fpos or {}
    node = S("symbol", S("lib_id", f"{lib}:{name}"), S("at", x, y, rot), S("unit", unit), S("body_style", 1),
             S("exclude_from_sim", Sym("no")), S("in_bom", Sym("yes" if in_bom else "no")), S("on_board", Sym("yes")),
             S("in_pos_files", Sym("yes")), S("dnp", Sym("yes" if dnp else "no")), S("uuid", uid()))
    for key in ("Reference", "Value", "Footprint", "Datasheet", "Description"):
        lp = prop(ls, key)
        v = {"Reference": ref, "Value": value if value is not None else (lp[2] if lp else name),
             "Footprint": footprint}.get(key, lp[2] if lp else "")
        if key in fpos:
            dx, dy, just = fpos[key]
            px, py = x + dx, y + dy
        else:
            at = find(lp, "at") if lp else None
            px, py = to_screen(x, y, rot, float(at[1]), float(at[2])) if at else (x, y)
            eff = find(lp, "effects") if lp else None
            j = find(eff, "justify") if eff else None
            just = " ".join(str(t) for t in j[1:]) if j else None
        lib_hidden = lp is not None and find(lp, "hide") is not None and find(lp, "hide")[1] == "yes"
        hidden = key in ("Footprint", "Datasheet", "Description") or lib_hidden or (key == "Value" and hide_value)
        # field angles are relative to the symbol: 90° on a rotated symbol reads horizontally
        p = S("property", key, v, S("at", px, py, 90 if rot in (90, 270) else 0))
        if hidden:
            p.append(S("hide", Sym("yes")))
        p.append(effects(just))
        node.append(p)
    placed = Placed(ls, ref, x, y, rot, unit)
    for n in placed.pins:
        node.append(S("pin", n, S("uuid", uid())))
    node.append(S("instances", S("project", NAME, S("path", sh.path, S("reference", ref), S("unit", unit)))))
    sh.add(node)
    return placed


def wire(sh, a, b):
    if a != b:
        sh.add(S("wire", S("pts", S("xy", *a), S("xy", *b)), S("stroke", S("width", 0), S("type", Sym("default"))),
                 S("uuid", uid())))


def junction(sh, p):
    sh.add(S("junction", S("at", *p), S("diameter", 0), S("color", 0, 0, 0, 0), S("uuid", uid())))


def no_connect(sh, p):
    sh.add(S("no_connect", S("at", *p), S("uuid", uid())))


def label(sh, name, p, ang, glob=None, shape="bidirectional"):
    glob = name in GLOBAL if glob is None else glob
    if glob:
        sh.add(S("global_label", name, S("shape", Sym(shape)), S("at", *p, ang), S("fields_autoplaced", Sym("yes")),
                 effects(JUST[ang]), S("uuid", uid()),
                 S("property", "Intersheetrefs", "${INTERSHEET_REFS}", S("at", *p, 0), S("hide", Sym("yes")),
                   effects(JUST[ang]))))
    else:
        sh.add(S("label", name, S("at", *p, ang), S("fields_autoplaced", Sym("yes")),
                 effects(JUST[ang] + " bottom"), S("uuid", uid())))


def text(sh, s, x, y, size=1.27):
    sh.add(S("text", s, S("exclude_from_sim", Sym("no")), S("at", x, y, 0), effects("left top", size), S("uuid", uid())))


def power(sh, net, p, out):
    if net == "GND":
        rot = {(0, 1): 0, (0, -1): 180, (1, 0): 90, (-1, 0): 270}[out]
    else:
        rot = {(0, -1): 0, (0, 1): 180, (1, 0): 270, (-1, 0): 90}[out]
    COUNT["#PWR"] += 1
    symbol(sh, "power", net, f"#PWR{COUNT['#PWR']:04d}", p[0], p[1], rot)


def pwr_flag(sh, p, out=(0, -1)):
    COUNT["#FLG"] += 1
    rot = {(0, -1): 0, (0, 1): 180, (1, 0): 270, (-1, 0): 90}[out]
    symbol(sh, "power", "PWR_FLAG", f"#FLG{COUNT['#FLG']:02d}", p[0], p[1], rot)
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

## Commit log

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2026-09-15 Footprints für alle Tastengrößen, README, Lizenz
    - Projekt-fp-lib-table für MX_Only (Submodul MX_Alps_Hybrid)
    - 17 Nicht-1u-Tasten auf passende Footprints getauscht, Schaltplan und PCB,
    Pads/Netze/Positionen unverändert
    - README (EN/DE) mit Suche nach einem Gehäuse-Designer
    - Lizenz CC BY-NC-SA 4.0
    - CLAUDE.md mit Projektstand
    [keyboard-fullsize.kicad_pcb, keyboard-fullsize.kicad_sch]
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2026-09-15 Umbenennung in convertible-keyboard-pcb, Wandel-Konzept Full-Size/TKL
    - KiCad-Dateien und Projektname umbenannt
    - README (EN/DE): Ziffernblock abbrechbar → TKL, Eckdaten beider Größen,
    Sollbruchstelle im Fahrplan
    - CLAUDE.md mit Wandel-Konzept und Pinbudget
    [convertible-keyboard-pcb.kicad_pcb, convertible-keyboard-pcb.kicad_sch]
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2026-09-15 ANSI-Alternativen: Backslash, Enter und linkes Shift
    - SW106 Backslash 1.5u (ROW2/COL13): ohne LED, Schalter auf der Platine um
    270° gedreht – nur so kollidiert er nicht mit dem ISO-Enter-Stabilisator
    - SW107 Enter 2.25u (ROW3/COL13) und SW108 Shift links 2.25u (ROW4/COL0)
    auf denselben Matrixpositionen wie ISO-Enter bzw. ISO-Shift
    - ISO-Enter SW71 im Schaltplan um 180° gedreht: Pin 2 = COL13, Pin 1 = Diode
    - Footprints mit dem Schaltplan verknüpft (Pfade fehlten seit kbplacer)
    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
    [convertible-keyboard-pcb.kicad_pcb, convertible-keyboard-pcb.kicad_sch]
2026-09-15 Einfarbige Hintergrundbeleuchtung (LEDs optional)
    - Neues Symbol keyboard:SW_MX_LED: Einheit A Schalter (Pins wie
    SW_Push_45deg), Einheit B LED mit Pin 3 = Anode, Pin 4 = Kathode –
    passend zu den ai03-LED-Footprints (KiCads SW_Push_LED ist umgekehrt belegt)
    - Alle Schalter außer ANSI-Backslash auf LED-Footprints umgestellt
    - Blatt "Backlight": je Taste LED-Einheit + 1k-Vorwiderstand an +5V,
    Kathoden auf BL_K; AO3400A low-side als PWM-Treiber (BL_PWM)
    - Caps-Lock- (SW58) und Num-Lock-LED (SW34) als Lock-Anzeige mit eigenem
    2N7002-Treiber (CAPS_LED, NUM_LED)
    - LED-Kathode bei SW71, SW76, SW107 auf die andere Seite gelegt (FLIPPED),
    sonst zu nah an den Stabi-Löchern der ISO/ANSI-A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
    [backlight.kicad_sch, convertible-keyboard-pcb.kicad_pcb, convertible-keyboard-pcb.kicad_sch]
2026-09-15 MCU-Blatt: RP2040, USB-C, Stromversorgung; README und CLAUDE.md
    - Blatt "MCU": RP2040 (QFN-56) mit W25Q16JVSS-Flash, 12-MHz-Quarz,
    AP2112K-3.3, USB-C (HRO TYPE-C-31-M-12, CC 5k1) mit USBLC6-2SC6,
    500-mA-Polyfuse, 27-Ω-Serienwiderständen, RESET- und BOOTSEL-Taster,
    SWD-Testpads, Entkopplung je Versorgungspin
    - Alle 30 GPIOs belegt: GPIO0–20 COL0–20, GPIO21–26 ROW0–5,
    GPIO27 BL_PWM, GPIO28 CAPS_LED, GPIO29 NUM_LED
    - Stabile UUIDs in den erzeugten Blättern, Beschriftungen aufgeräumt
    - Neue Bauteile mit dem Schaltplan verknüpft, vorerst unplatziert unterhalb
    der Tasten
    ERC: 0 Meldungen, Parität sauber. DRC: nur fehlender Umriss, die gewollten
    ISO/ANSI-NPTH-Überlappungen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
    [backlight.kicad_sch, convertible-keyboard-pcb.kicad_pcb, convertible-keyboard-pcb.kicad_sch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]
2026-09-15 tools/: Generator-Skripte für Schaltplan und Platine
    - gen_sch.py (Stufen ANSI, Beleuchtung, MCU), check_sch.py (ERC +
    Netzlisten-Soll/Ist), sync_pcb.py (PCB aus Netzliste, Platzierung, DRC),
    kicadlib.py, place_override.json, build.sh --overwrite
    - analysis/: Kollisionsprüfungen ISO/ANSI, die zum gedrehten,
    unbeleuchteten ANSI-Backslash und den FLIPPED-LED-Pads geführt haben
    - Basis wird per git show aus Commit 95ce8fa gelesen
    - Pin-UUIDs der LED-Einheit auf dem Hauptblatt jetzt deterministisch:
    zwei Neuaufbauten ergeben identische Schaltplandateien
    - README (EN/DE) für tools/, Verweis in README und CLAUDE.md
    [convertible-keyboard-pcb.kicad_pcb, convertible-keyboard-pcb.kicad_sch]
2026-09-15 Eigene Caps-/Num-Lock-Anzeige über dem Navigationsblock
    - Caps- und Num-Taste gehören wieder zur normalen Beleuchtung (BL_K) –
    bei eingeschaltetem Licht war der Lock-Zustand in der Taste kaum erkennbar
    - Je Anzeige 1k an +5V und zwei LEDs parallel zur Wahl: 3 mm THT
    (D121 Caps, D123 Num) oder 0805 SMD (D122, D124), Treiber Q2/Q3 wie bisher
    - Platz im Spalt zwischen Druck/Rollen/Pause und Einfg/Pos1/BildAuf, also auf
    dem TKL-Teil: bleibt auch nach dem Abbrechen des Ziffernblocks erhalten
    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
    [backlight.kicad_sch, convertible-keyboard-pcb.kicad_pcb, convertible-keyboard-pcb.kicad_sch]
2026-09-15 MCU-Blatt: UUIDs passend zum Neuaufbau
    Die Lock-Anzeigen werden vor dem MCU-Blatt erzeugt und verschieben dessen
    fortlaufende UUIDs; ohne diese Datei passen die Platinenpfade der
    MCU-Bauteile nicht zum Schaltplan. Inhaltlich unverändert.
    [mcu.kicad_sch]
2026-09-15 Lock-Anzeigen zusätzlich klassisch über dem Numpad (Standard)
    - Zweites Paar Caps-/Num-Lock-Anzeigen rechts oben über dem Numpad:
    0805 bestückt (D126 Caps, D128 Num), 3-mm-THT vorgesehen (D125, D127, DNP)
    - Paar über dem Navigationsblock bleibt für die TKL vorgesehen, alle LEDs DNP
    - Jede Position mit eigenem 1k (R127–R130, bestückt), damit auch beide Paare
    gleichzeitig mit voller Helligkeit gehen; Treiber Q2/Q3 unverändert
    - DNP wird in tools/sync_pcb.py auf die Footprints übertragen
    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
    [backlight.kicad_sch, convertible-keyboard-pcb.kicad_pcb, convertible-keyboard-pcb.kicad_sch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]
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2026-09-15 Lock-Anzeigen nur noch als 0805, TKL nur Caps Lock über BildAuf
    - 3-mm-THT-Varianten entfernt (D121, D123, D125, D127)
    - Über dem Numpad: D128 Num und D126 Caps mittig auf Höhe der F-Reihe,
    bestückt
    - TKL: nur noch Caps Lock (D122, DNP) mittig über BildAuf in der Lücke
    zwischen F-Reihe und Zahlenreihe – Num Lock fällt mit dem Numpad ohnehin
    weg, daher Num-Anzeige D124 samt R128 entfernt
    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
    [backlight.kicad_sch, convertible-keyboard-pcb.kicad_pcb, convertible-keyboard-pcb.kicad_sch]
2026-09-15 Lock-Anzeigen über dem Numpad rechtsbündig
    Num Lock (D128) über *, Caps Lock (D126) über -, wie bei den meisten
    Tastaturen; Vorwiderstände auf der Rückseite mitverschoben.
    [convertible-keyboard-pcb.kicad_pcb]
2026-09-15 Anschlüsse für Unified Daughterboard (Pico-EZmate und JST-SH)
    - J2 Molex Pico-EZmate 78171-0004 (uDB S1, C4, C5-EZM) und
    J3 JST-SH SM04B-SRSS-TB (uDB C3, C5-JSH), beide nicht bestückt
    - Parallel zur USB-C-Buchse J1: Pin 1 VBUS, 2 D-, 3 D+, 4 + MP GND –
    Belegung aus den KiCad-Quellen von UDB-S und UDB-C-JSH gelesen (1:1-Kabel)
    - J1 bleibt standardmäßig bestückt; für ein Daughterboard J1 weglassen und
    J2 oder J3 bestücken
    - Footprints vorerst unplatziert neben den übrigen MCU-Bauteilen
    - README (EN/DE) und CLAUDE.md ergänzt, LED-Entscheidung (THT oder
    Reverse-Mount-SMD) als offener Punkt vermerkt
    ERC 0, Parität sauber, DRC ohne neue Meldungen.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
    [convertible-keyboard-pcb.kicad_pcb, mcu.kicad_sch]
2026-09-15 Tasten-LEDs als Reverse-Mount-SMD (Standard), THT-Variante vorgehalten
    - Schalter wieder mit 2-Pin-Symbol und ai03-NoLED-Footprints; jede Taste
    hat eine eigene LED LEDn (gleiche Nummer) auf der Rückseite unter dem
    LED-Fenster (Schaltermitte +5,08 mm) – Drähte und Netze unverändert
    - LED: XINGLIGHT XL-3216UWC-FB, weiß, LCSC C3646935, maschinell bestückt
    - Eigener Footprint LED_1206_ReverseMount_XL-3216 nach dem JLC/EasyEDA-
    Footprint (Pads 1,0 x 1,524 mm bei +-1,651, Aussparung 2,2 x 1,9 mm):
    Pad-Innenkante 0,2 mm von der Aussparung, Eckradius 0,5 mm zum Fräsen.
    KiCads generischer Reverse-Mount-Footprint passt nicht zu diesem Teil
    (Loch in Längsrichtung kleiner als die Li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
    [backlight.kicad_sch, convertible-keyboard-pcb.kicad_pcb, convertible-keyboard-pcb.kicad_sch]
2026-09-15 Vorläufige Platzierung von Controller, USB und Treibern
    Alles auf der Rückseite in Flächen, die zwischen Schalterpins, Dioden,
    Vorwiderständen und LED-Aussparungen frei sind:
    - Esc/F1-Lücke: USB-C J1 an der Oberkante (Kontakte nach innen), darunter
    ESD-Schutz, CC- und Schirmbeschaltung, 27-Ohm-Widerstände, Polyfuse,
    3,3-V-Regler, Daughterboard-Stecker J2 (Pico-EZmate) und J3 (JST-SH)
    - Streifen unter der F-Reihe: Flash, RP2040 (USB/QSPI-Seite nach links,
    Quarz rechts), Entkopplung in Reihen über und unter dem Chip, Quarz,
    BOOTSEL- und RESET-Taster, SWD-Testpads
    - F4/F5-Lücke: Treiber Q1–Q3 mit Gate- und Pulldown-Widerständen
    - Referenztexte der dicht gesetzten Entkopplung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
    [convertible-keyboard-pcb.kicad_pcb]
2026-09-15 Platinenumriss und Sollbruchstelle, Alternativ-LEDs in der Stückliste
    - Umriss: Tastenfeld + 1,3 mm rundum (Ecken r = 1 mm). Die 1,3 mm sind
    nötig, weil die Stabi-Löcher von Leertaste, Num 0 und Num+ über das reine
    Tastenfeld hinausragen. USB-C J1 sitzt bündig mit der Oberkante
    - Sollbruchstelle: 2 mm breiter Schlitz bei x = 378,6 mit vier
    Mouse-Bite-Stegen (Footprint Breakaway_Tab_MouseBite, BRK1–BRK4). Jeder
    Steg hat einen lochfreien Kanal für bis zu drei Bahnen pro Lage:
    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
    [backlight.kicad_sch, convertible-keyboard-pcb.kicad_pcb]
2026-09-15 Tastenfeld geroutet
    - Spalten vorn (Schalter zu Schalter), Zeilen hinten als Schiene unter jeder
    Tastenreihe, ROW1–ROW5 über die Kanäle der Mouse-Bite-Stege zum Numpad
    - LED-Versorgung: +5V und BL_K als Schienen je Reihe, verbunden über
    Längsstränge am linken Rand und links neben dem Numpad, je ein Übergang
    über BRK2 (+5V) und BRK3 (BL_K)
    - Kurze Verbindungen je Taste (Schalter → Diode, Widerstand → LED) als
    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
    [convertible-keyboard-pcb.kicad_pcb]
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
